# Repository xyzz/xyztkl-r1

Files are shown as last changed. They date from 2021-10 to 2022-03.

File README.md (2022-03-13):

# A second revision of this case design is available at [https://github.com/xyzz/xyztkl-r2](https://github.com/xyzz/xyztkl-r2)

# xyztkl rev1

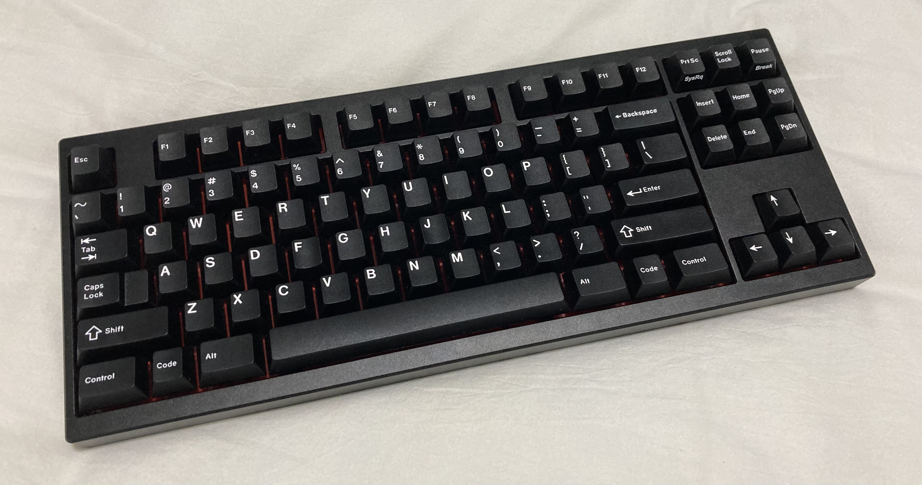
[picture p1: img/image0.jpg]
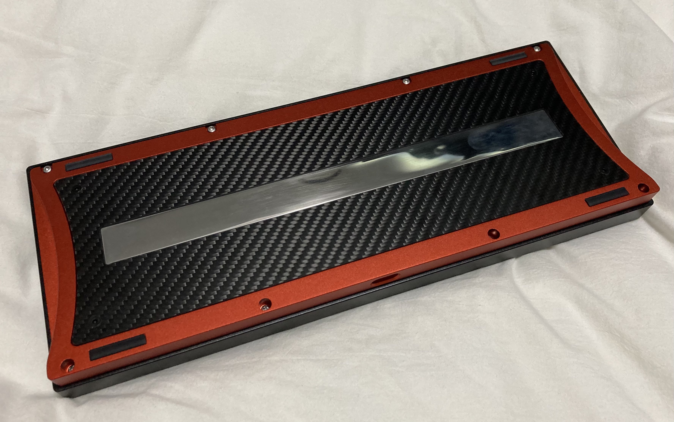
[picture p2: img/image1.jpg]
 

## License

CC0 apart from the switch footprints and component STEP models, see LICENSE.txt.

## Known issues

- The PCB is a bit hard to align
- The steel piece is very long and thin, it may warp during machining

## Parts list

- top
- bottom
- weight-inside: you need two of these, it is already noted in the tech drawing
- weight-outside
- cf-accent: while provided .STEP is 2mm thick, recommend reducing to ~1.8mm so that it looks nicer around the SS accent; countersunk screw holes
- dboard - this uses a custom daughterboard. See notes about JST cable before; should be 1mm thick
- pcb - the included PCB is using STM32F103 (or a compatible clone), you will need an ST-LINK to program the included bootloader; recommend matching the color to the color of the bottom piece if possible; should be 1.6mm thick
- jst cable: 100mm, reverse orientation (pins 1-4 on one side map to 4-1 on the other) - note that this is the opposite of what ai03 unified daughterboard uses, if you use a wrong cable you risk killing the pcb

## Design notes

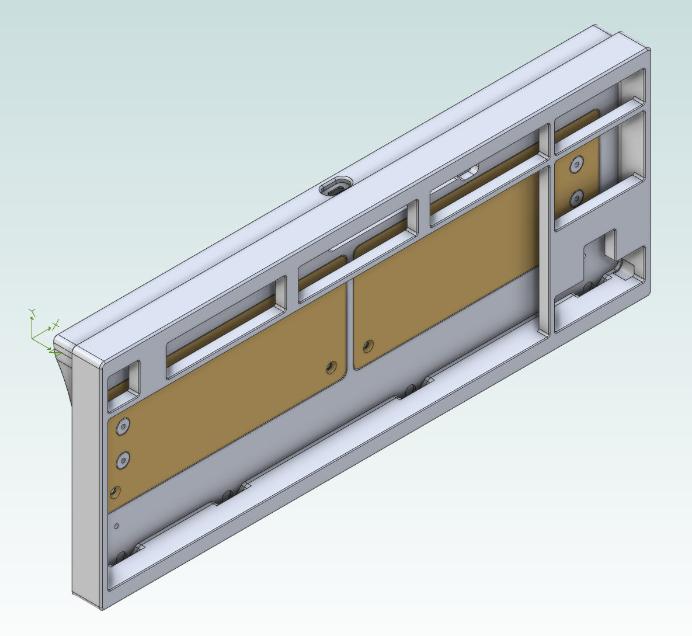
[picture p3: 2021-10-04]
cosmetic/overall-01.png

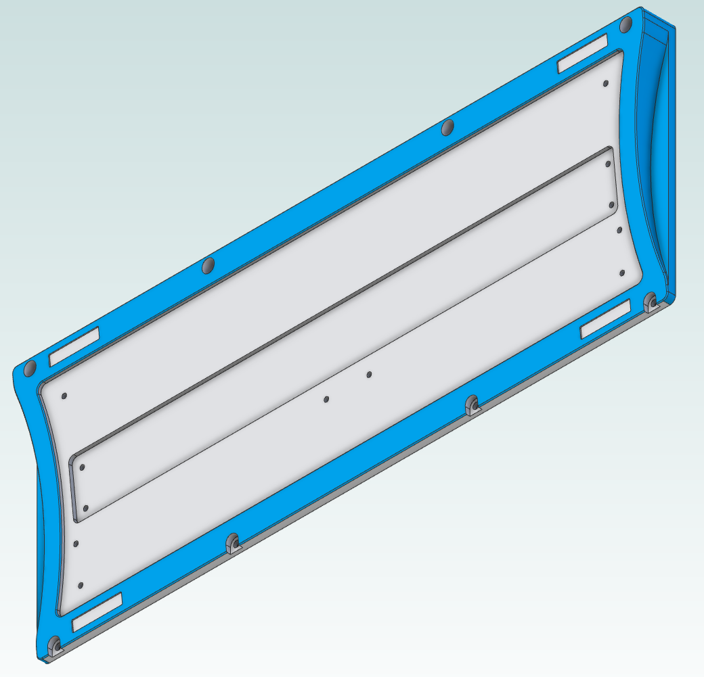
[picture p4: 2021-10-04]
cosmetic/bottom-03.png

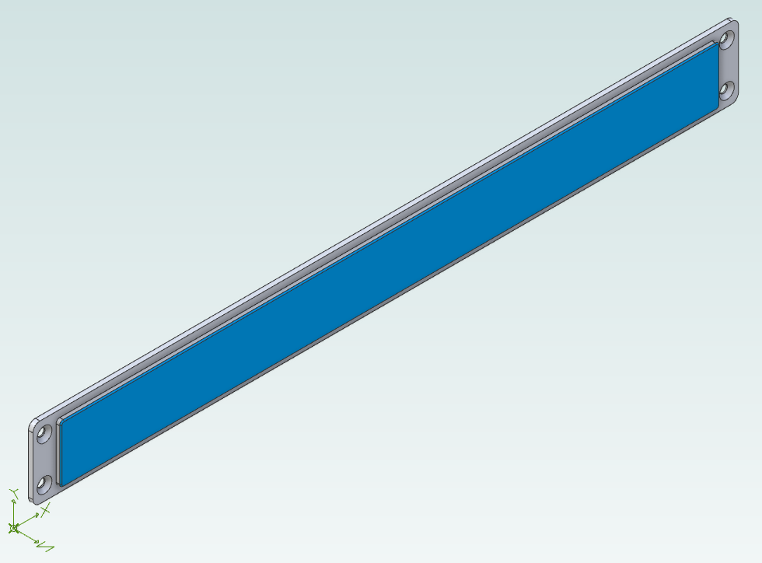
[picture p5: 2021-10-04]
cosmetic/weight-outside-01.png

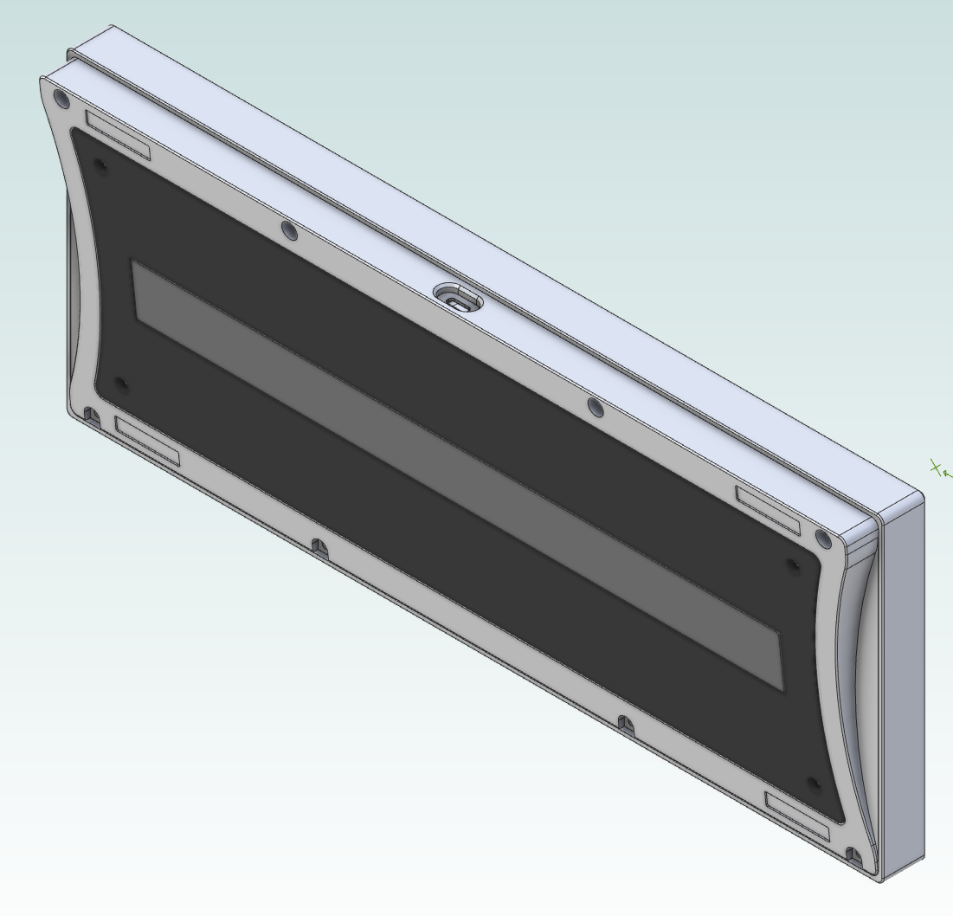
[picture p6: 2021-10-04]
cosmetic/overall-02.png

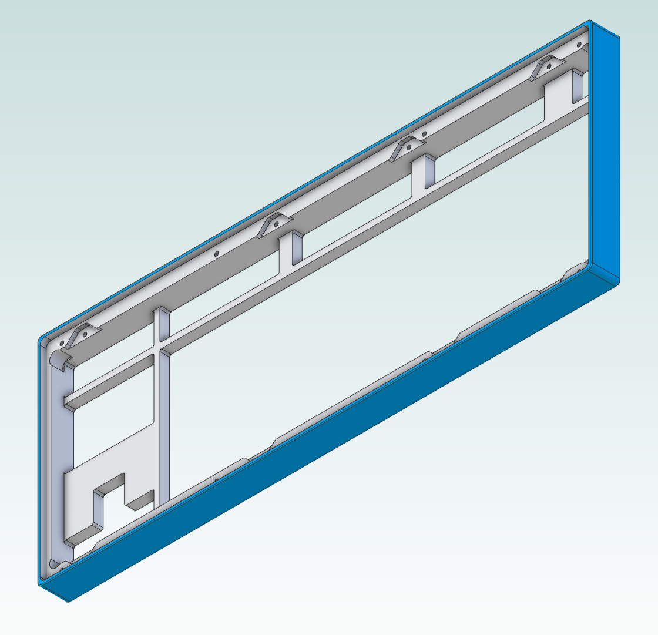
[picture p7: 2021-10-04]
cosmetic/top-03.png

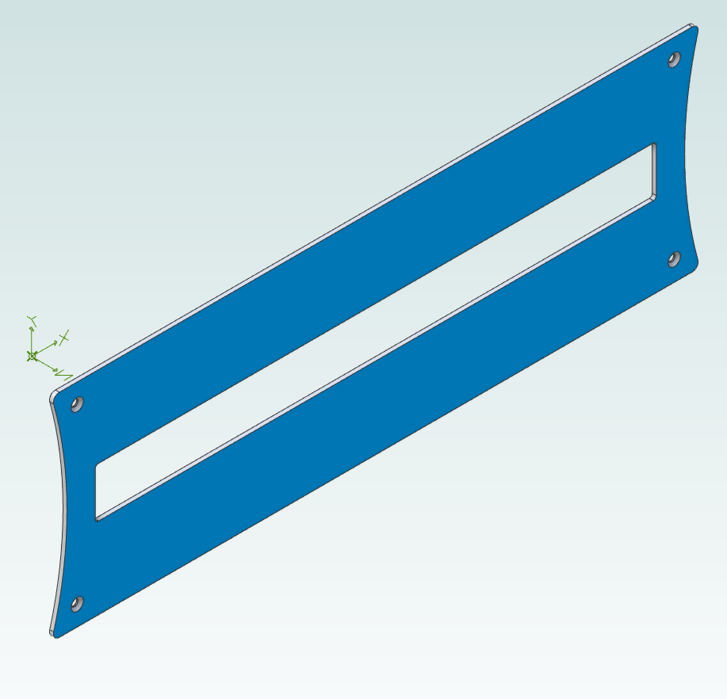
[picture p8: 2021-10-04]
cosmetic/cf-accent-01.png

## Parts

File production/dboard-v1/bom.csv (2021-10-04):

Comment | Designator | Footprint | LCSC
5.1k | R2,R1 | Resistor_SMD:R_0603_1608Metric | C23186
Mount-M2 | MH1,MH2 | MountingHole:MountingHole_3.2mm_M3_Pad_Via
1M | R3 | Resistor_SMD:R_0805_2012Metric | C17514
4.7n | C1 | Capacitor_SMD:C_0603_1608Metric | C53987
USB_C_Receptacle_USB2.0 | J1 | Connector_USB:USB_C_Receptacle_HRO_TYPE-C-31-M-12 | C165948
Conn_01x04_MountingPin | J2 | Connector_JST:JST_SH_SM04B-SRSS-TB_1x04-1MP_P1.00mm_Horizontal | C160404

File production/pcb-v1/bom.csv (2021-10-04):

Comment | Designator | Footprint | LCSC
KEYSW | K_0,K_1,K_2,K_3,K_4,K_5,K_6,K_7,K_8,K_9,K_10,K_11,K_12,K_13,K_15,K_16,K_17,K_18,K_19,K_20,K_21,K_22,K_23,K_24,K_25,K_26,K_27,K_28,K_29,K_30,K_31,K_32,K_33,K_35,K_36,K_37,K_38,K_39,K_40,K_41,K_42,K_43,K_44,K_45,K_46,K_48,K_49,K_50,K_52,K_53,K_54,K_55,K_56,K_57,K_58,K_59,K_60,K_61,K_62,K_65,K_66,K_67,K_68,K_69,K_70,K_71,K_72,K_73,K_74,K_76,K_77,K_86,K_87,K_88 | MX_Only:MXOnly-1U-NoLED
D | D_0,D_1,D_2,D_3,D_4,D_5,D_6,D_7,D_8,D_9,D_10,D_11,D_12,D_13,D_14,D_15,D_16,D_17,D_18,D_19,D_20,D_21,D_22,D_23,D_24,D_25,D_26,D_27,D_28,D_29,D_30,D_31,D_32,D_33,D_34,D_35,D_36,D_37,D_38,D_39,D_40,D_41,D_42,D_43,D_44,D_45,D_46,D_47,D_48,D_49,D_50,D_51,D_52,D_53,D_54,D_55,D_56,D_57,D_58,D_59,D_60,D_61,D_62,D_63,D_64,D_65,D_66,D_67,D_68,D_69,D_70,D_71,D_72,D_73,D_74,D_75,D_76,D_77,D_78,D_79,D_80,D_81,D_82,D_83,D_84,D_85,D_86,D_87,D_88 | Diode_SMD:D_SOD-123 | C81598
KEYSW | K_14 | MX_Only:MXOnly-1U
KEYSW | K_34,K_47 | MX_Only:MXOnly-1.5U-NoLED
KEYSW | K_51 | MX_Only:MXOnly-1.75U
KEYSW | K_63,K_64 | MX_Only:MXOnly-2.25U-NoLED
KEYSW | K_75 | MX_Only:MXOnly-1.75U-NoLED
1.25 | K_78,K_79,K_80,K_82,K_83,K_84,K_85 | MX_Only:MXOnly-1.25U-NoLED
6.25 | K_81 | MX_Only:MXOnly-6.25U-ReversedStabilizers-NoLED
~7 | K_181 | MX_Only:MXOnly-7U-ReversedStabilizers-NoLED
~1.5 | K_178,K_180,K_183,K_185 | MX_Only:MXOnly-1.5U-NoLED
~1 | K_179,K_184 | MX_Only:MXOnly-1U-NoLED
Conn_01x04 | J1 | Connector_JST:JST_SH_SM04B-SRSS-TB_1x04-1MP_P1.00mm_Horizontal | C160404
MX-NoLED | K_175 | MX_Only:MXOnly-2.75U-NoLED
MX-NoLED | K_130 | MX_Only:MXOnly-2U-NoLED
8MHz | Y1 | Crystal:Crystal_SMD_5032-2Pin_5.0x3.2mm | C115962
20p | C9,C10 | Capacitor_SMD:C_0603_1608Metric | C1648
10u | C7 | Capacitor_SMD:C_0603_1608Metric | C19702
100n | C2,C3,C4,C5,C6,C8 | Capacitor_SMD:C_0603_1608Metric | C14663
10k | R1 | Resistor_SMD:R_0603_1608Metric | C25804
STM32F103C8Tx | U3 | Package_QFP:LQFP-48_7x7mm_P0.5mm
1u | C1,C12,C11 | Capacitor_SMD:C_0603_1608Metric | C15849
SWDIO | J3 | TestPoint:TestPoint_Pad_D1.5mm
SWCLK | J4 | TestPoint:TestPoint_Pad_D1.5mm
GND | J5 | TestPoint:TestPoint_Pad_D1.5mm
XC6206P332MR | U2 | Package_TO_SOT_SMD:SOT-23 | C5446
500mA | F1 | Fuse:Fuse_1206_3216Metric | C369159
1.5k | R2 | Resistor_SMD:R_0603_1608Metric | C22843
3.3v | J2 | TestPoint:TestPoint_Pad_D1.5mm
SRV05-4 | U1 | Package_TO_SOT_SMD:SOT-23-6 | C85364
MX-NoLED | K_151 | MX_Only:MXOnly-1.25U-FLIPPED
680 | R3,R4 | Resistor_SMD:R_0603_1608Metric | C23228

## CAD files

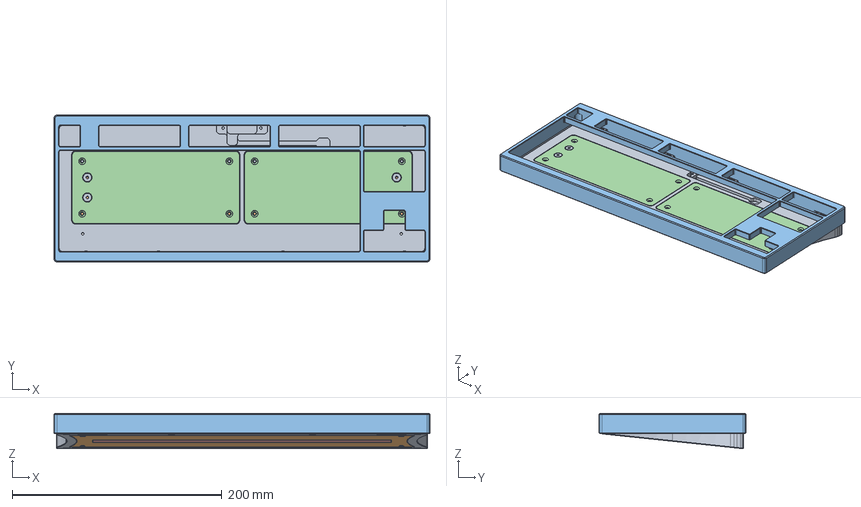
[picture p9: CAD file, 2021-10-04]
assembled.stp
358.6 x 140.0 x 33.7 mm
bottom
cf-accent
top
weight-inside x 2
weight-outside

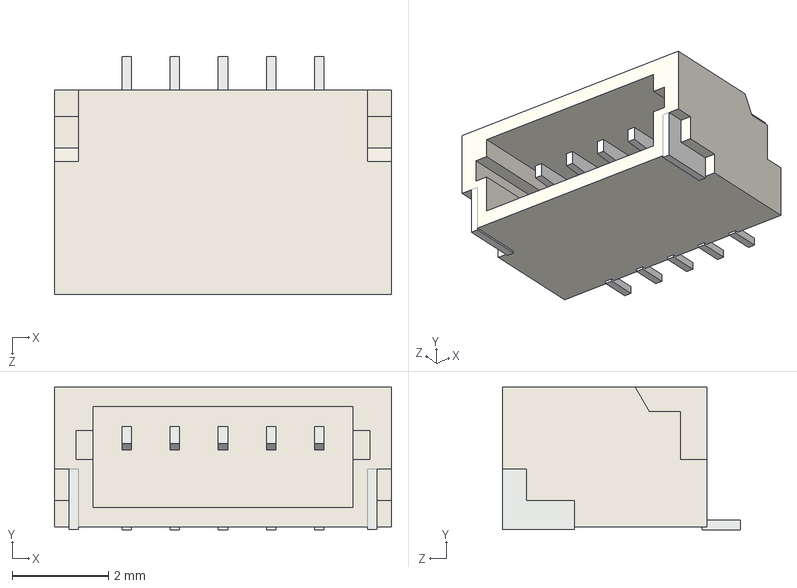
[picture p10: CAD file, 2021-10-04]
dboard/JST_SM05B-SRSS-TB.STEP
7.00 x 2.96 x 4.95 mm

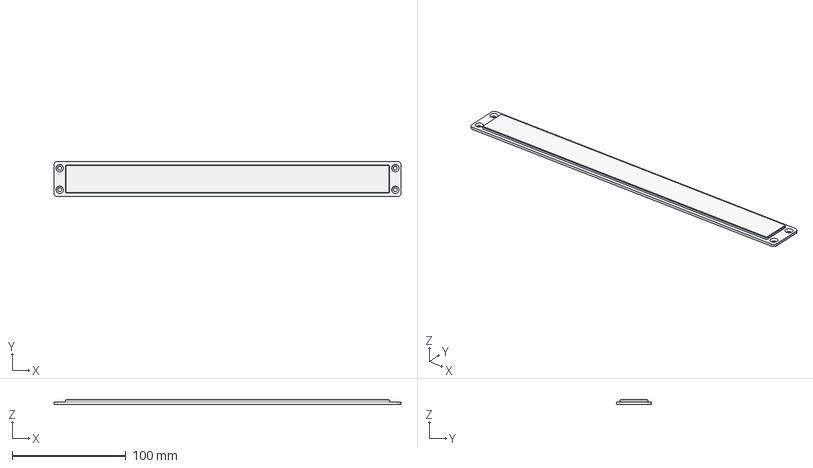
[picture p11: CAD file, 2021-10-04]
parts/weight-outside.stp
305.0 x 31.0 x 4.00 mm

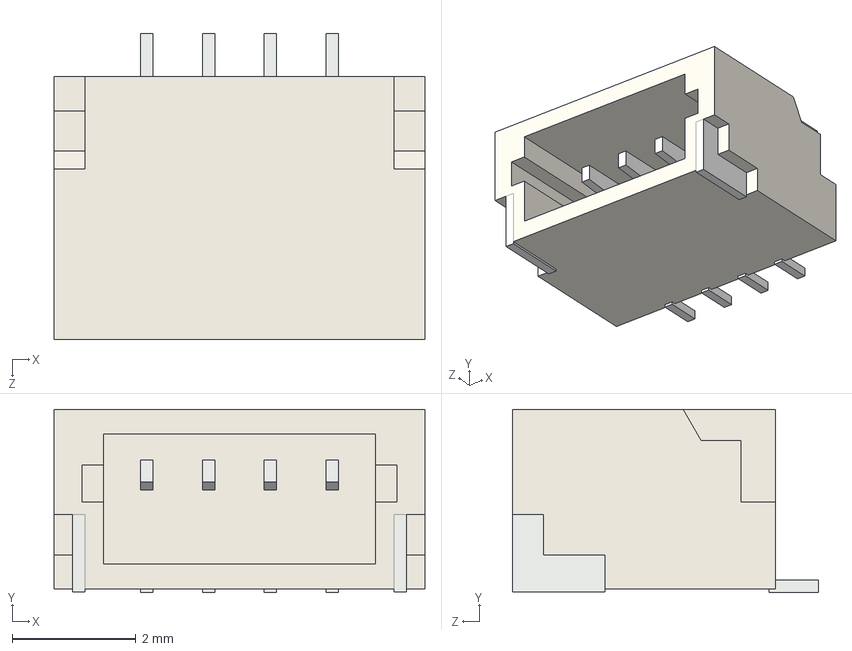
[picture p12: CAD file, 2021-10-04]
pcb/JST-SM04B-SRSS-TB.STEP
6.00 x 2.96 x 4.95 mm

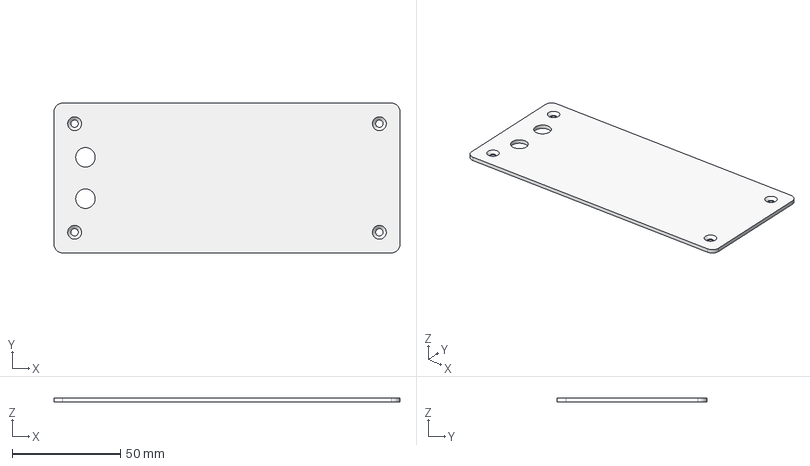
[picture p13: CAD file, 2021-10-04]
parts/weight-inside.stp
159.5 x 69.0 x 2.00 mm

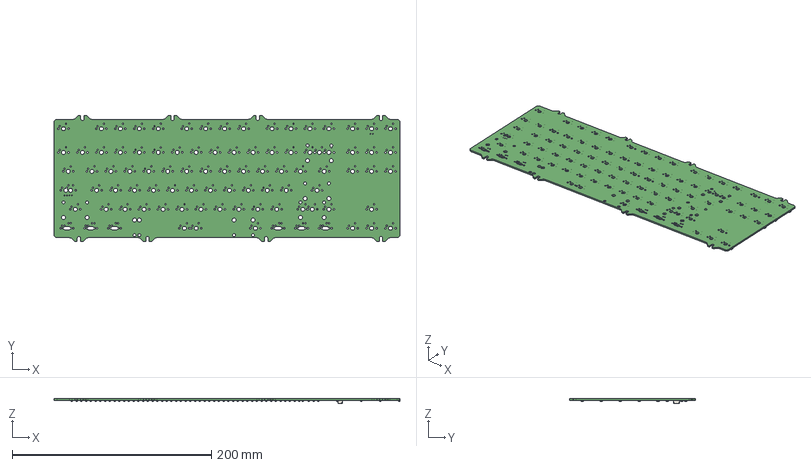
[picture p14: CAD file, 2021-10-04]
pcb/keyboard.step
347.7 x 127.1 x 4.66 mm

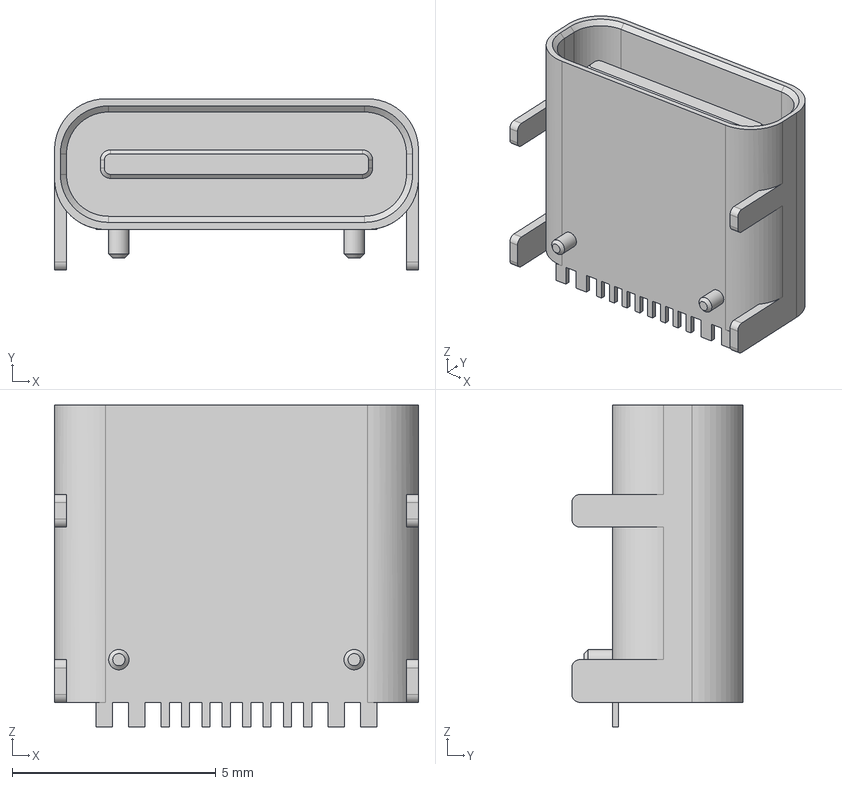
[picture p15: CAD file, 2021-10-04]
dboard/HRO-TYPE-C-31-M-12.step
8.94 x 4.21 x 7.90 mm

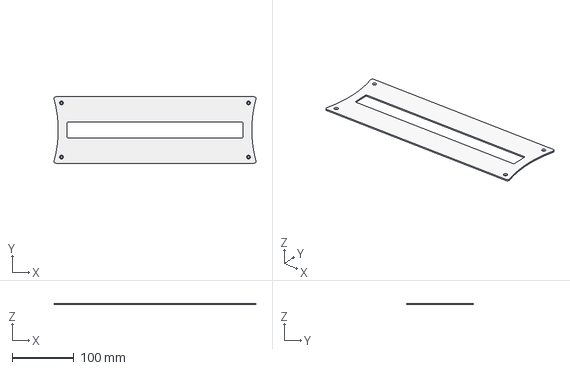
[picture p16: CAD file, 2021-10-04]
parts/cf-accent.stp
328.0 x 108.0 x 2.00 mm

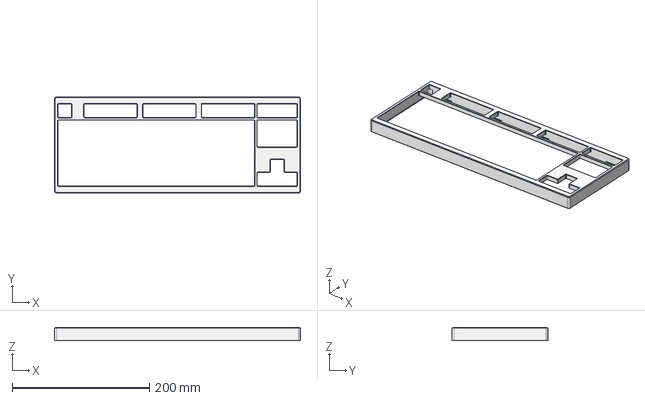
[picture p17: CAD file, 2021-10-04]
parts/top.stp
358.6 x 140.0 x 19.3 mm

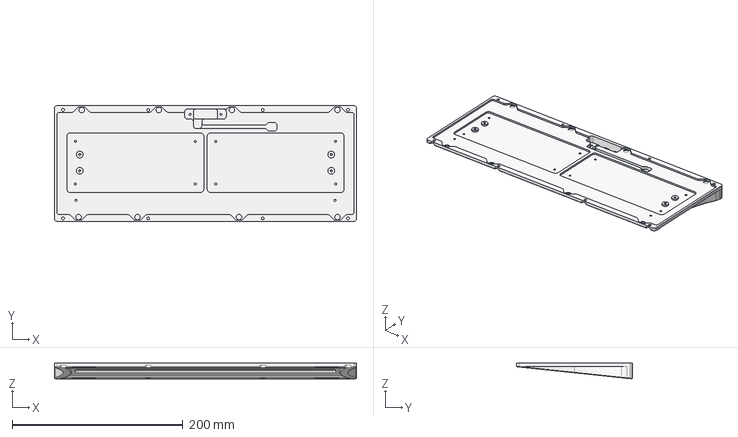
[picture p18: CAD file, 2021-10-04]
parts/bottom.stp
354.2 x 135.6 x 18.4 mm

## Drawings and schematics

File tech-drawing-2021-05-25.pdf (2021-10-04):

Scale | Sheet
1:1 | 1 OF 13

### Cosmetic requirements for surfaces indicated in BLUE - No scratches, dents, marks - Consistent anodization finish: no discoloration, no blemishes - No hanging/hook marks

### See included QC.PDF for more detail

Version 2021-05-21

### Part list: - bottom.step - top.step - (2x) weight-inside.step - weight-outside.step - cf-accent.step

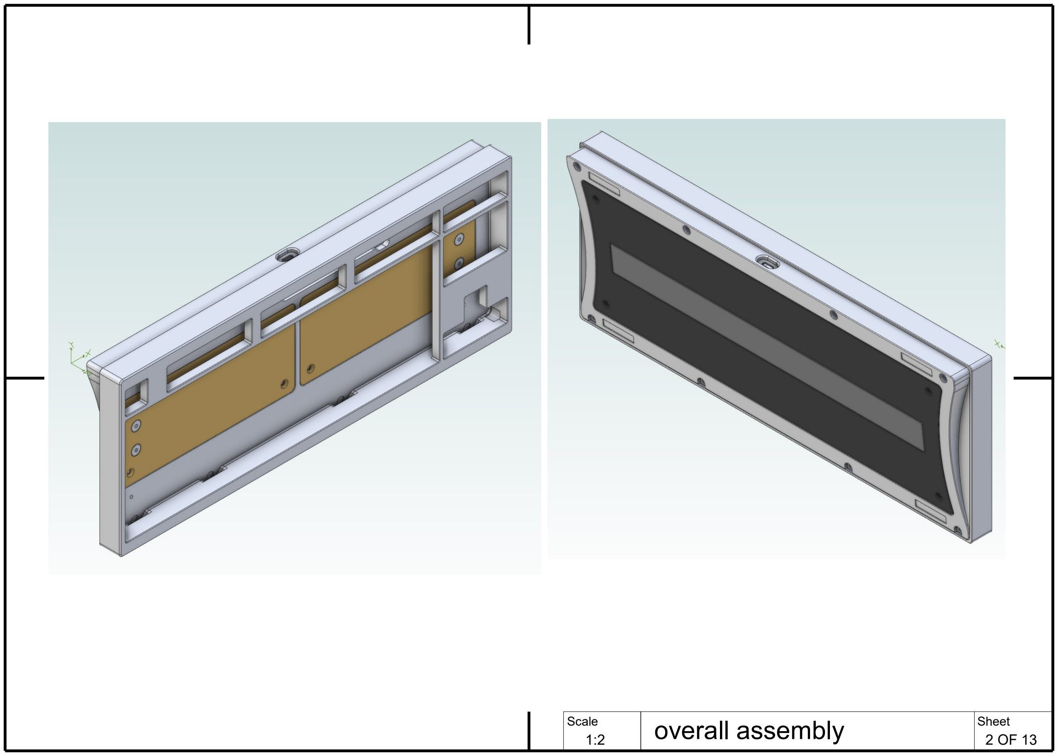
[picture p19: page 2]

Scale | | Sheet
1:2 | overall assembly | 2 OF 13

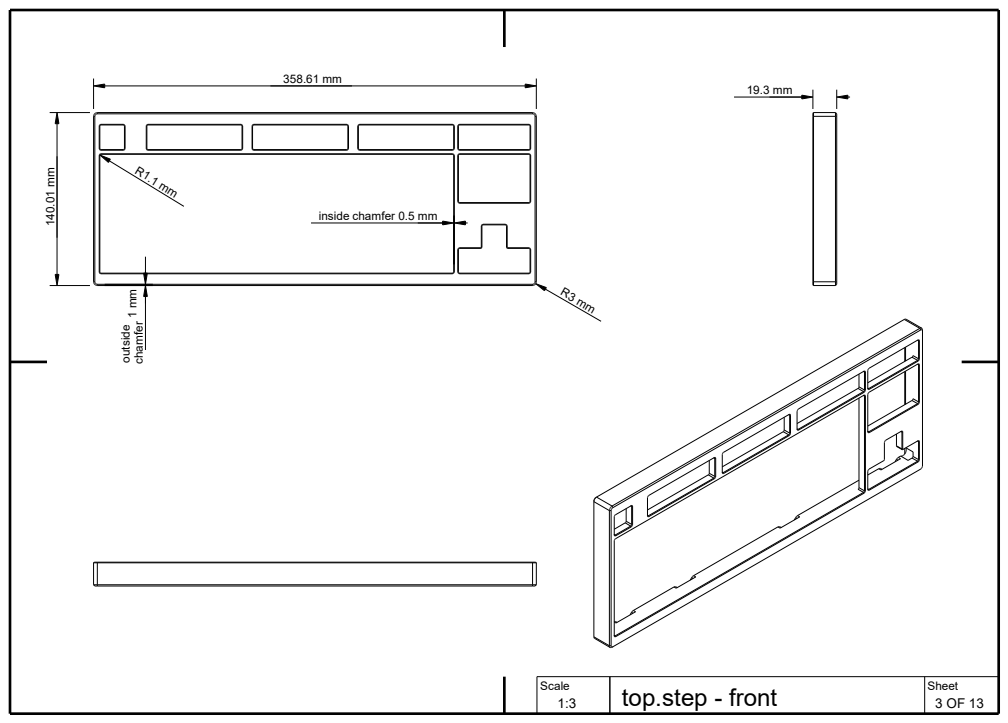
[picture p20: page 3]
Scale; Sheet; top.step - front

R1.1 mm 1 mm outside chamfer

inside chamfer 0.5 mm

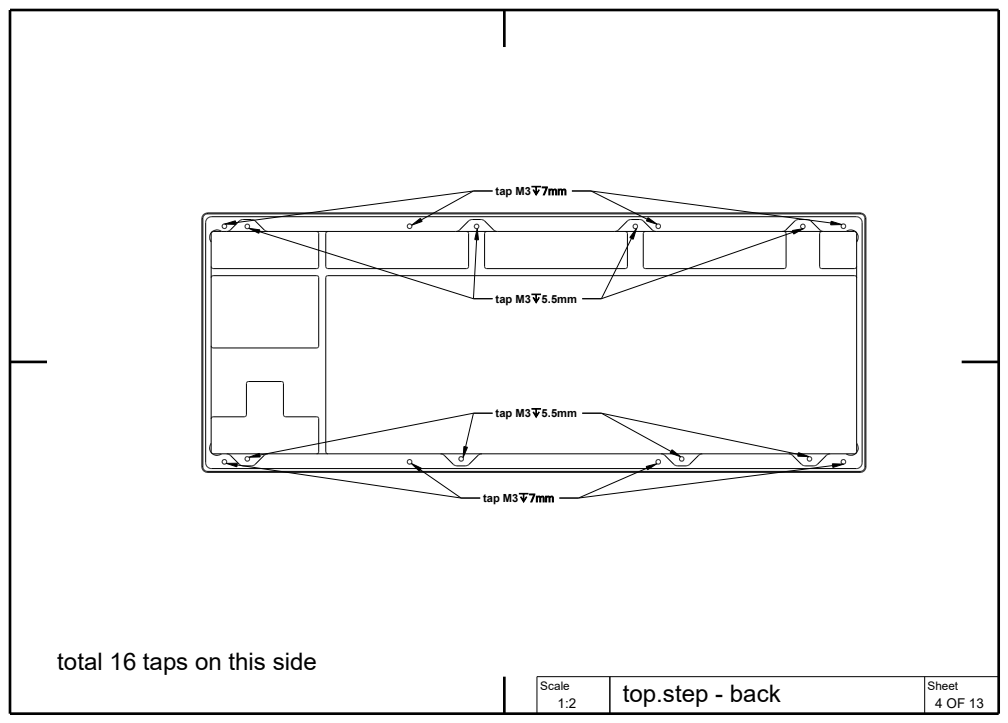
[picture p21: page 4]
tap M3x7mm; tap M3x5.5mm; Scale; Sheet

total 16 taps on this side

top.step - back

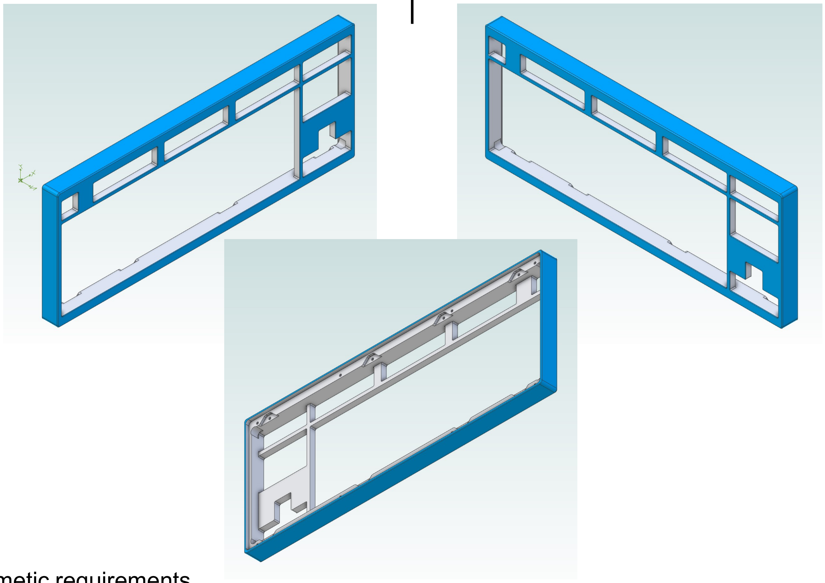
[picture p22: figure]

Scale | Sheet
1:2 | 5 OF 13 top.step - cosmetic surfaces

cosmetic requirements
for surfaces indicated in BLUE
see first page and QC.PDF for details

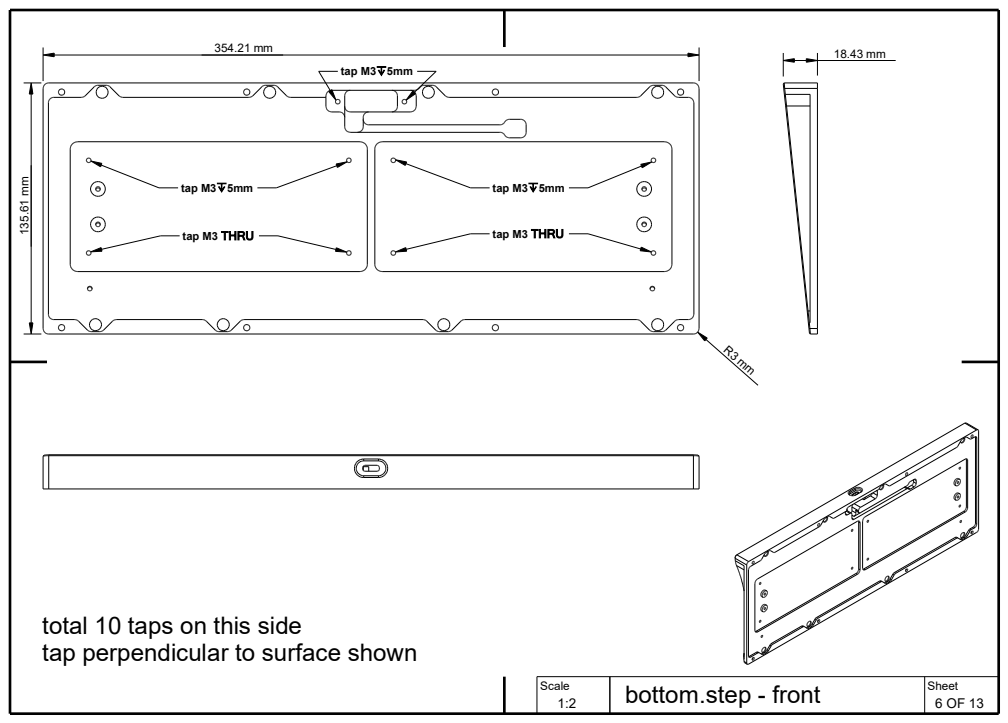
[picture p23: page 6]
tap M3x5mm; tap M3 THRU; Scale; Sheet

total 10 taps on this side
tap perpendicular to surface shown

bottom.step - front

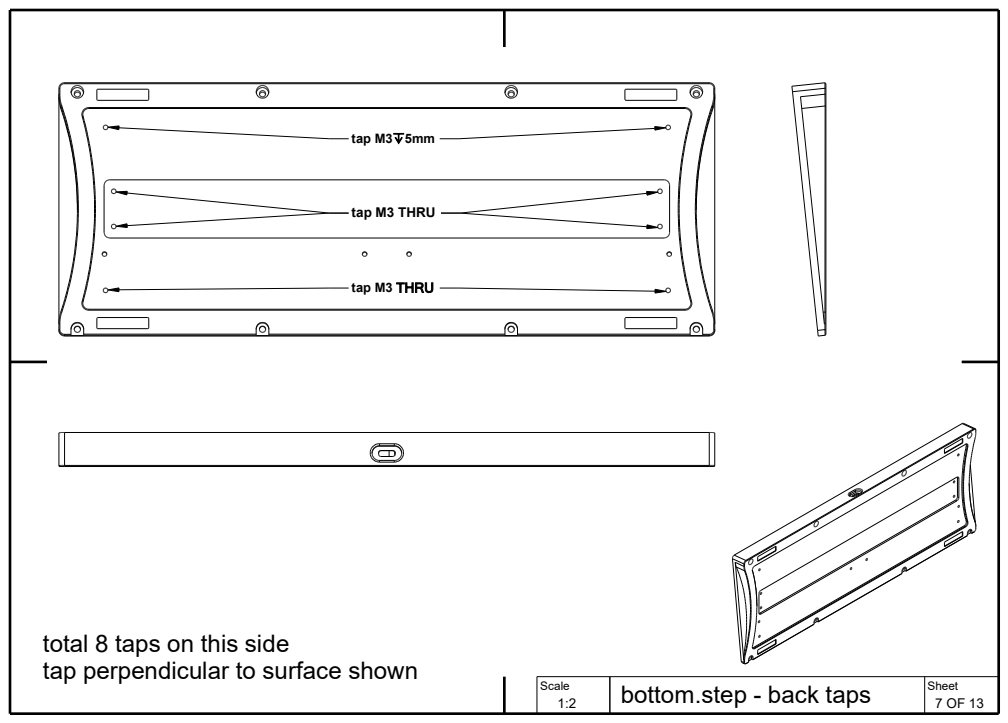
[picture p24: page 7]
tap M3 THRU; tap M3x5mm; Scale; Sheet; bottom.step - back taps

total 8 taps on this side
tap perpendicular to surface shown

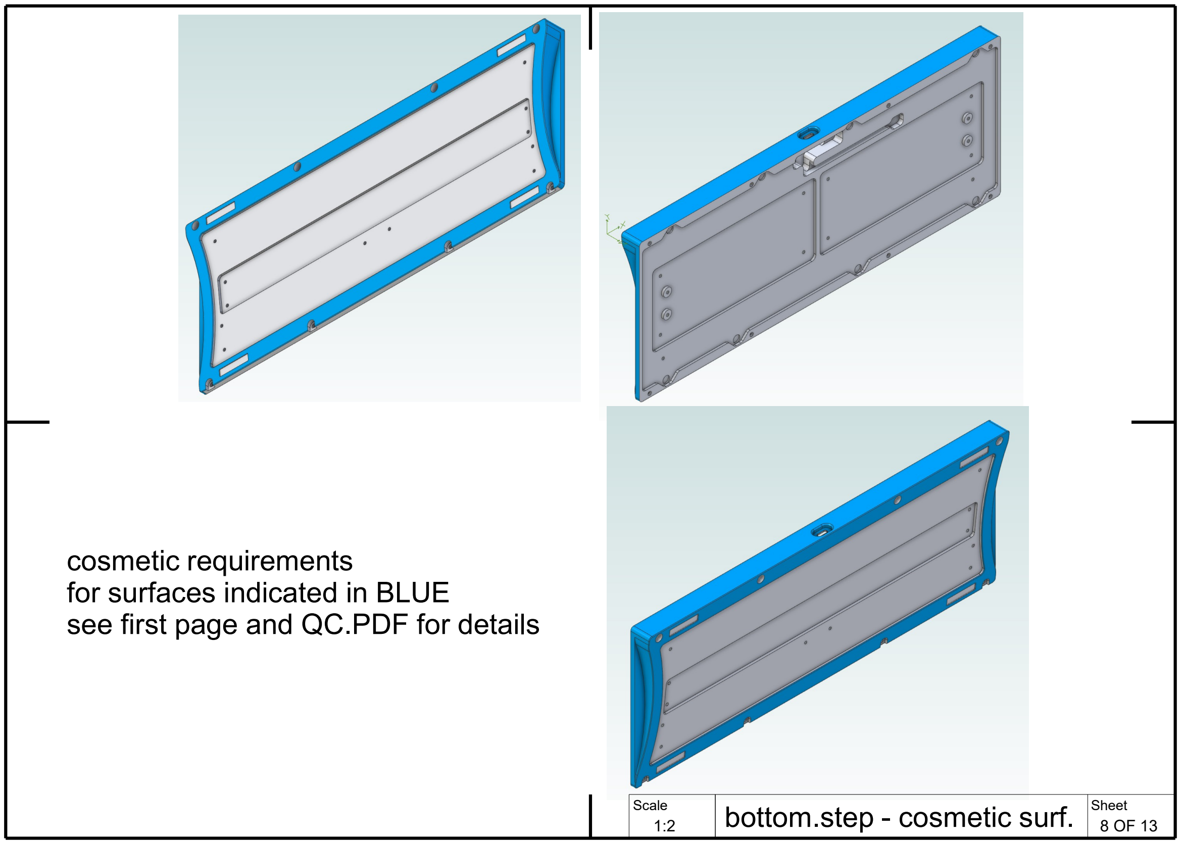
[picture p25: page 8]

Scale | Sheet
1:2 | 8 OF 13

cosmetic requirements
for surfaces indicated in BLUE
see first page and QC.PDF for details

bottom.step - cosmetic surf.

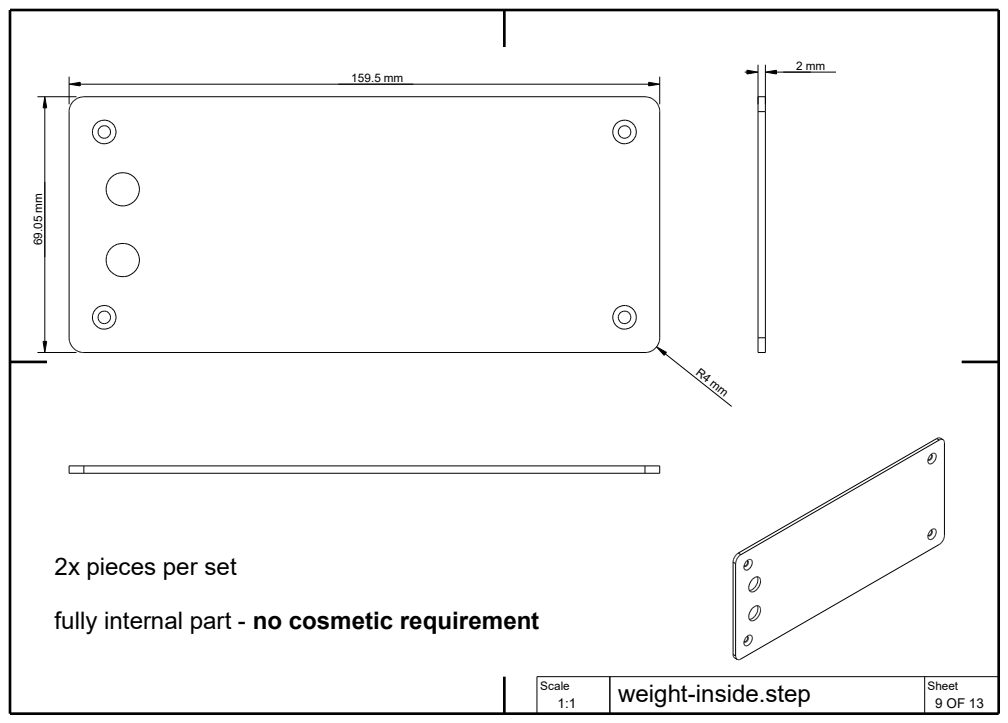
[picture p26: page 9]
Scale; Sheet; weight-inside.step

2x pieces per set

fully internal part - no cosmetic requirement

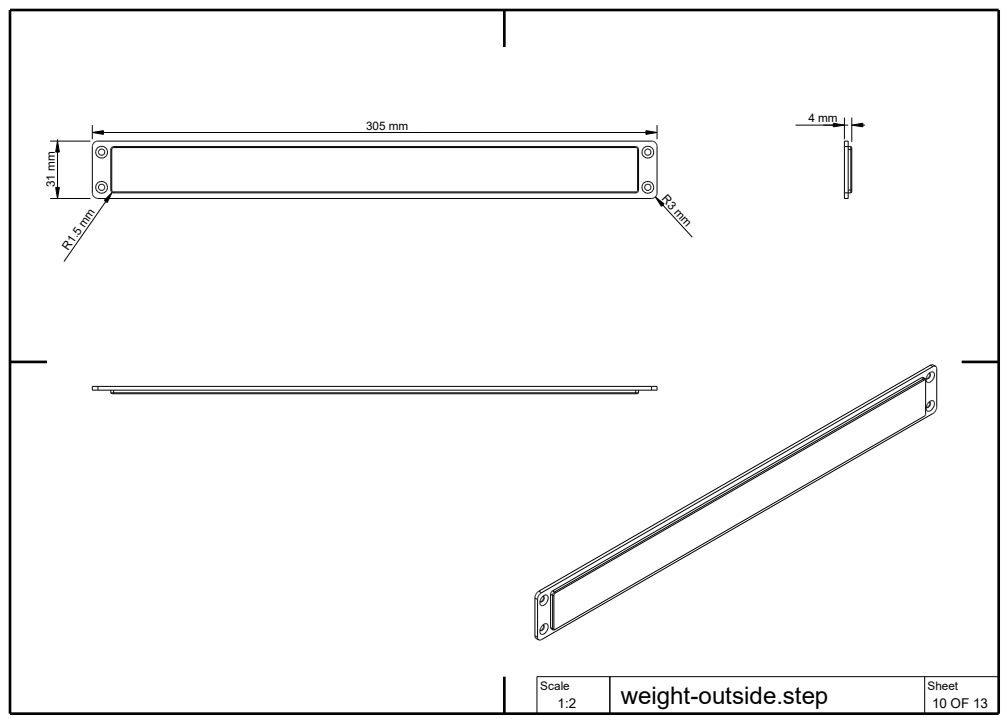
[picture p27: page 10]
Scale; Sheet; weight-outside.step

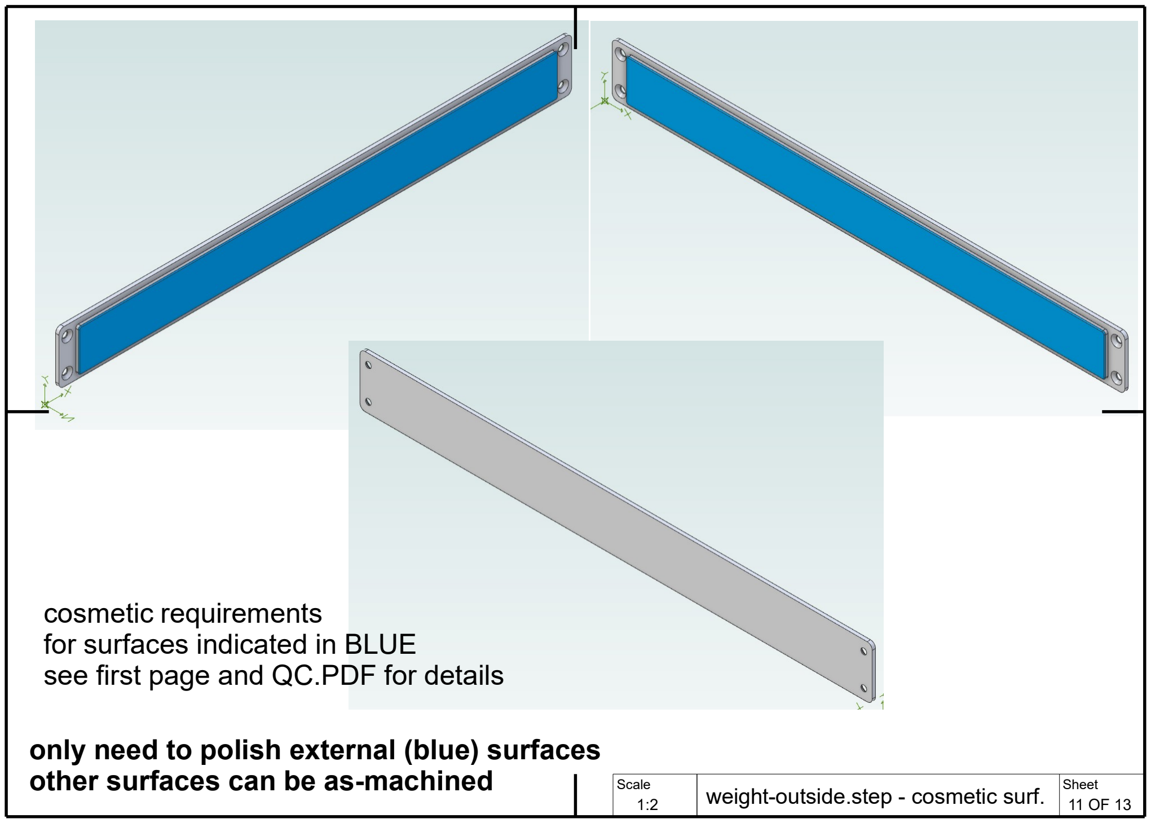
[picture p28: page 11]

Scale | | Sheet
1:2 | weight-outside.step - cosmetic surf. | 11 OF 13

cosmetic requirements
for surfaces indicated in BLUE
see first page and QC.PDF for details

only need to polish external (blue) surfaces other surfaces can be as-machined

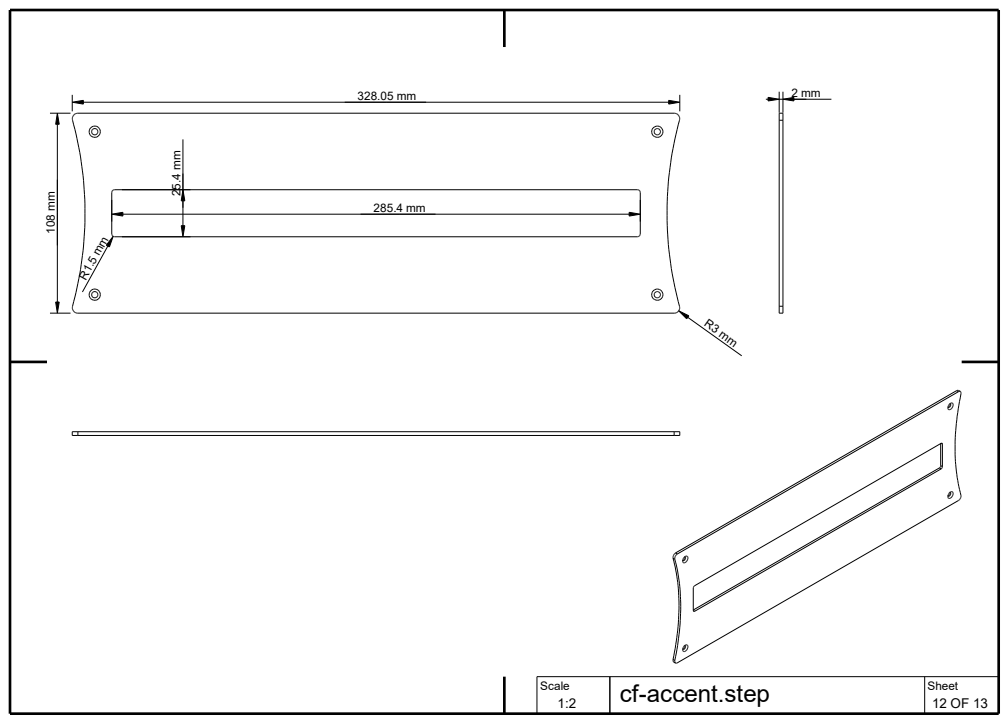
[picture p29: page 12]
Scale; Sheet; cf-accent.step

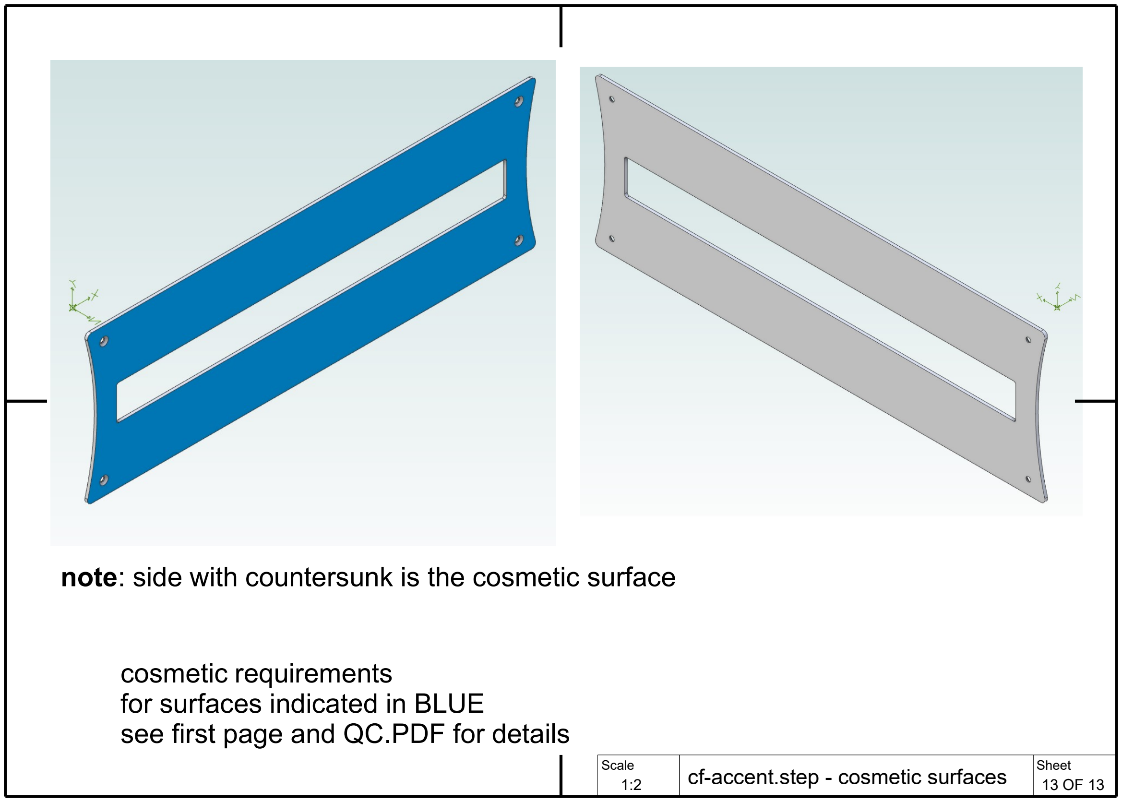
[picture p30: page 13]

Scale | Sheet
1:2 | 13 OF 13 cf-accent.step - cosmetic surfaces

cosmetic requirements
for surfaces indicated in BLUE
see first page and QC.PDF for details note: side with countersunk is the cosmetic surface

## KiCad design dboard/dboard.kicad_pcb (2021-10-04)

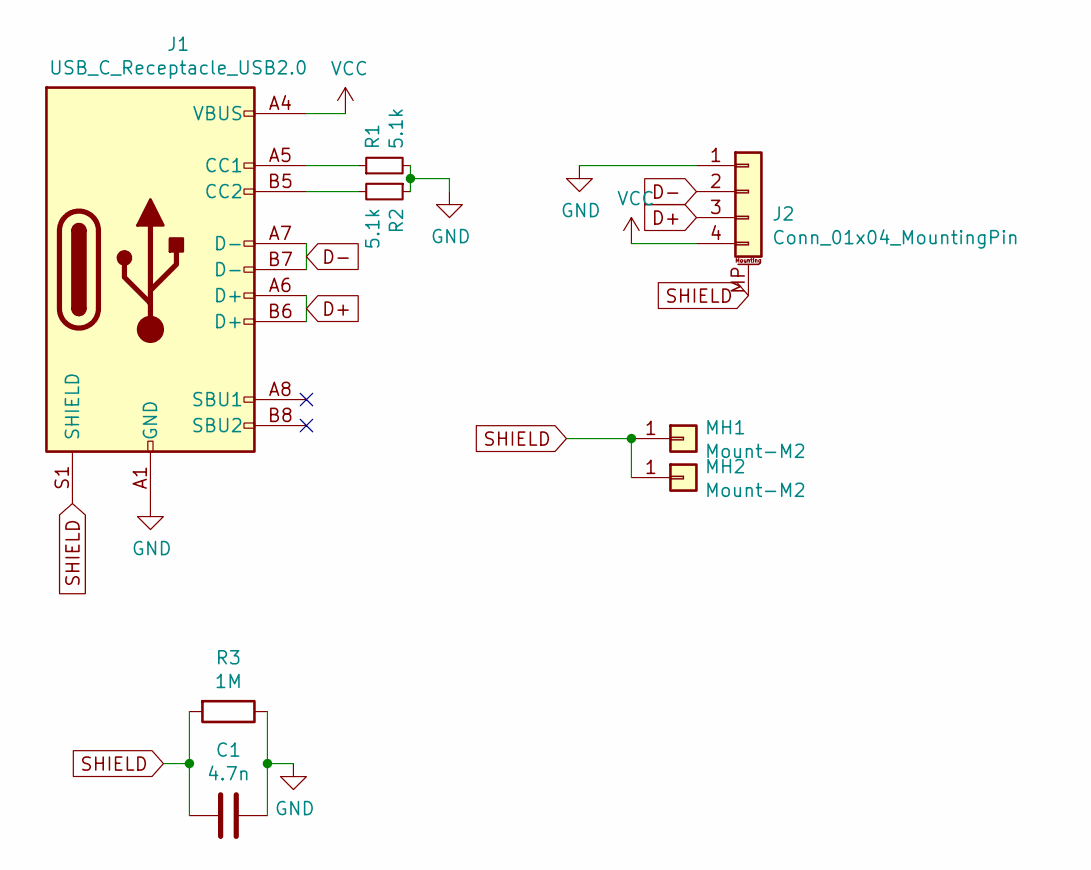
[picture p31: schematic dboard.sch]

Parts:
C1: 4.7n; C_0603_1608Metric; LCSC C53987
J1: USB_C_Receptacle_USB2.0; USB_C_Receptacle_HRO_TYPE-C-31-M-12; LCSC C165948
J2: Conn_01x04_MountingPin; JST_SH_SM04B-SRSS-TB_1x04-1MP_P1.00mm_Horizontal; LCSC C160404
MH1, MH2: Mount-M2; MountingHole_3.2mm_M3_Pad_Via
R1, R2: 5.1k; R_0603_1608Metric; LCSC C23186
R3: 1M; R_0805_2012Metric; LCSC C17514

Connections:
D+: J1.A6 (D+), J1.B6 (D+), J2.3
D-: J1.A7 (D-), J1.B7 (D-), J2.2
GND: C1.1, J1.A1 (GND), J1.A12 (GND), J1.B1 (GND), J1.B12 (GND), J2.1, R1.2, R2.1, R3.1
unnamed: J1.A5 (CC1), R1.1
unnamed: J1.B5 (CC2), R2.2
SHIELD: C1.2, J1.S1 (SHIELD), J2.MP (MountPin), MH1.1, MH2.1, R3.2
VCC: J1.A4 (VBUS), J1.A9 (VBUS), J1.B4 (VBUS), J1.B9 (VBUS), J2.4

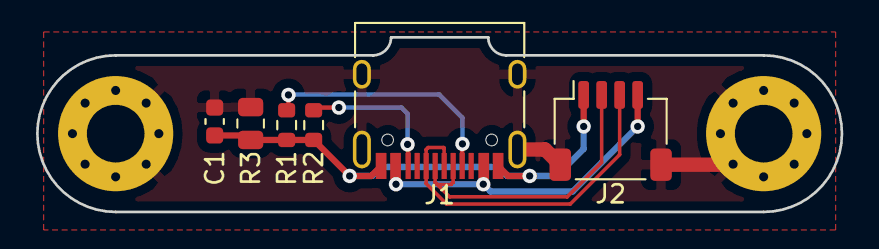
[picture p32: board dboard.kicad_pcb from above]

Board: 2 copper layers, 44.7 x 9.7 mm, 8 parts (0 on the bottom side), 7 nets.

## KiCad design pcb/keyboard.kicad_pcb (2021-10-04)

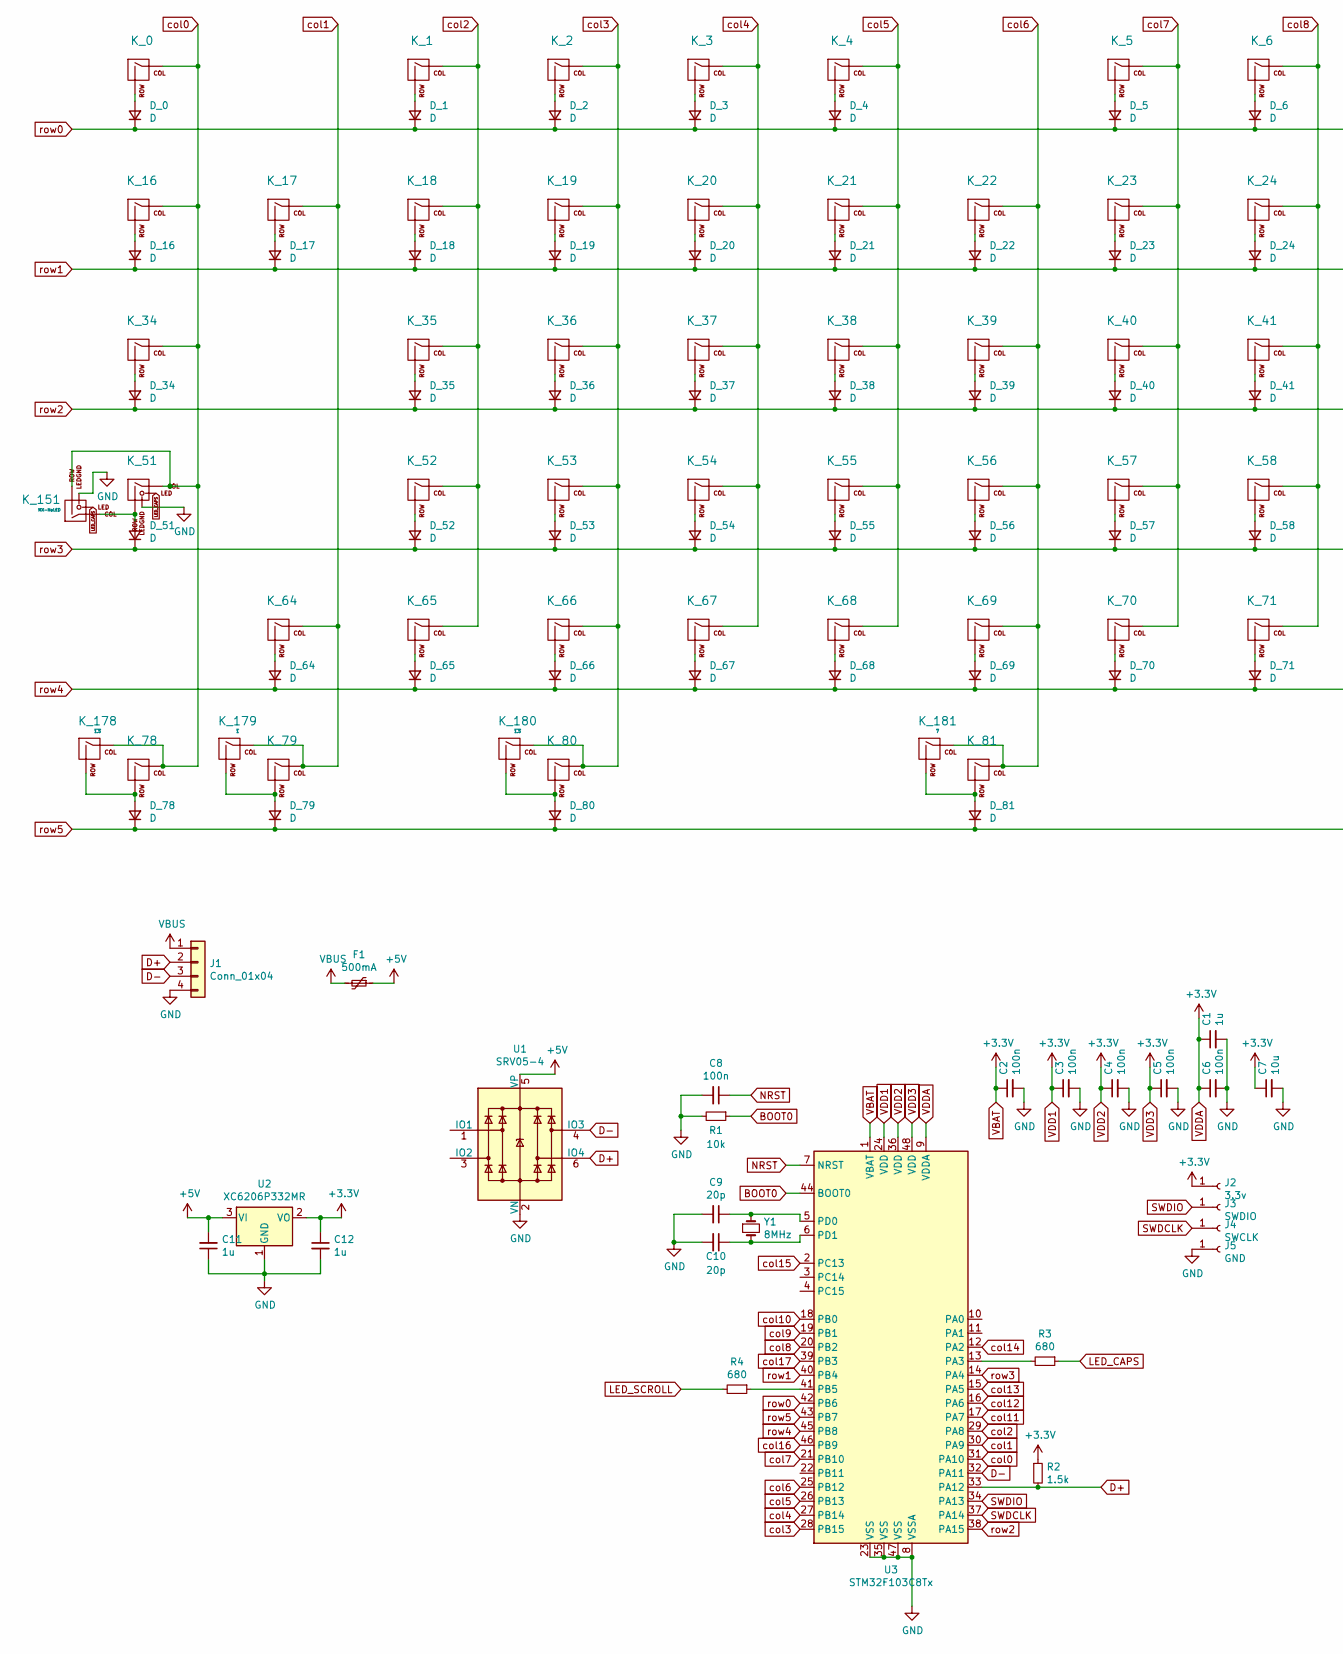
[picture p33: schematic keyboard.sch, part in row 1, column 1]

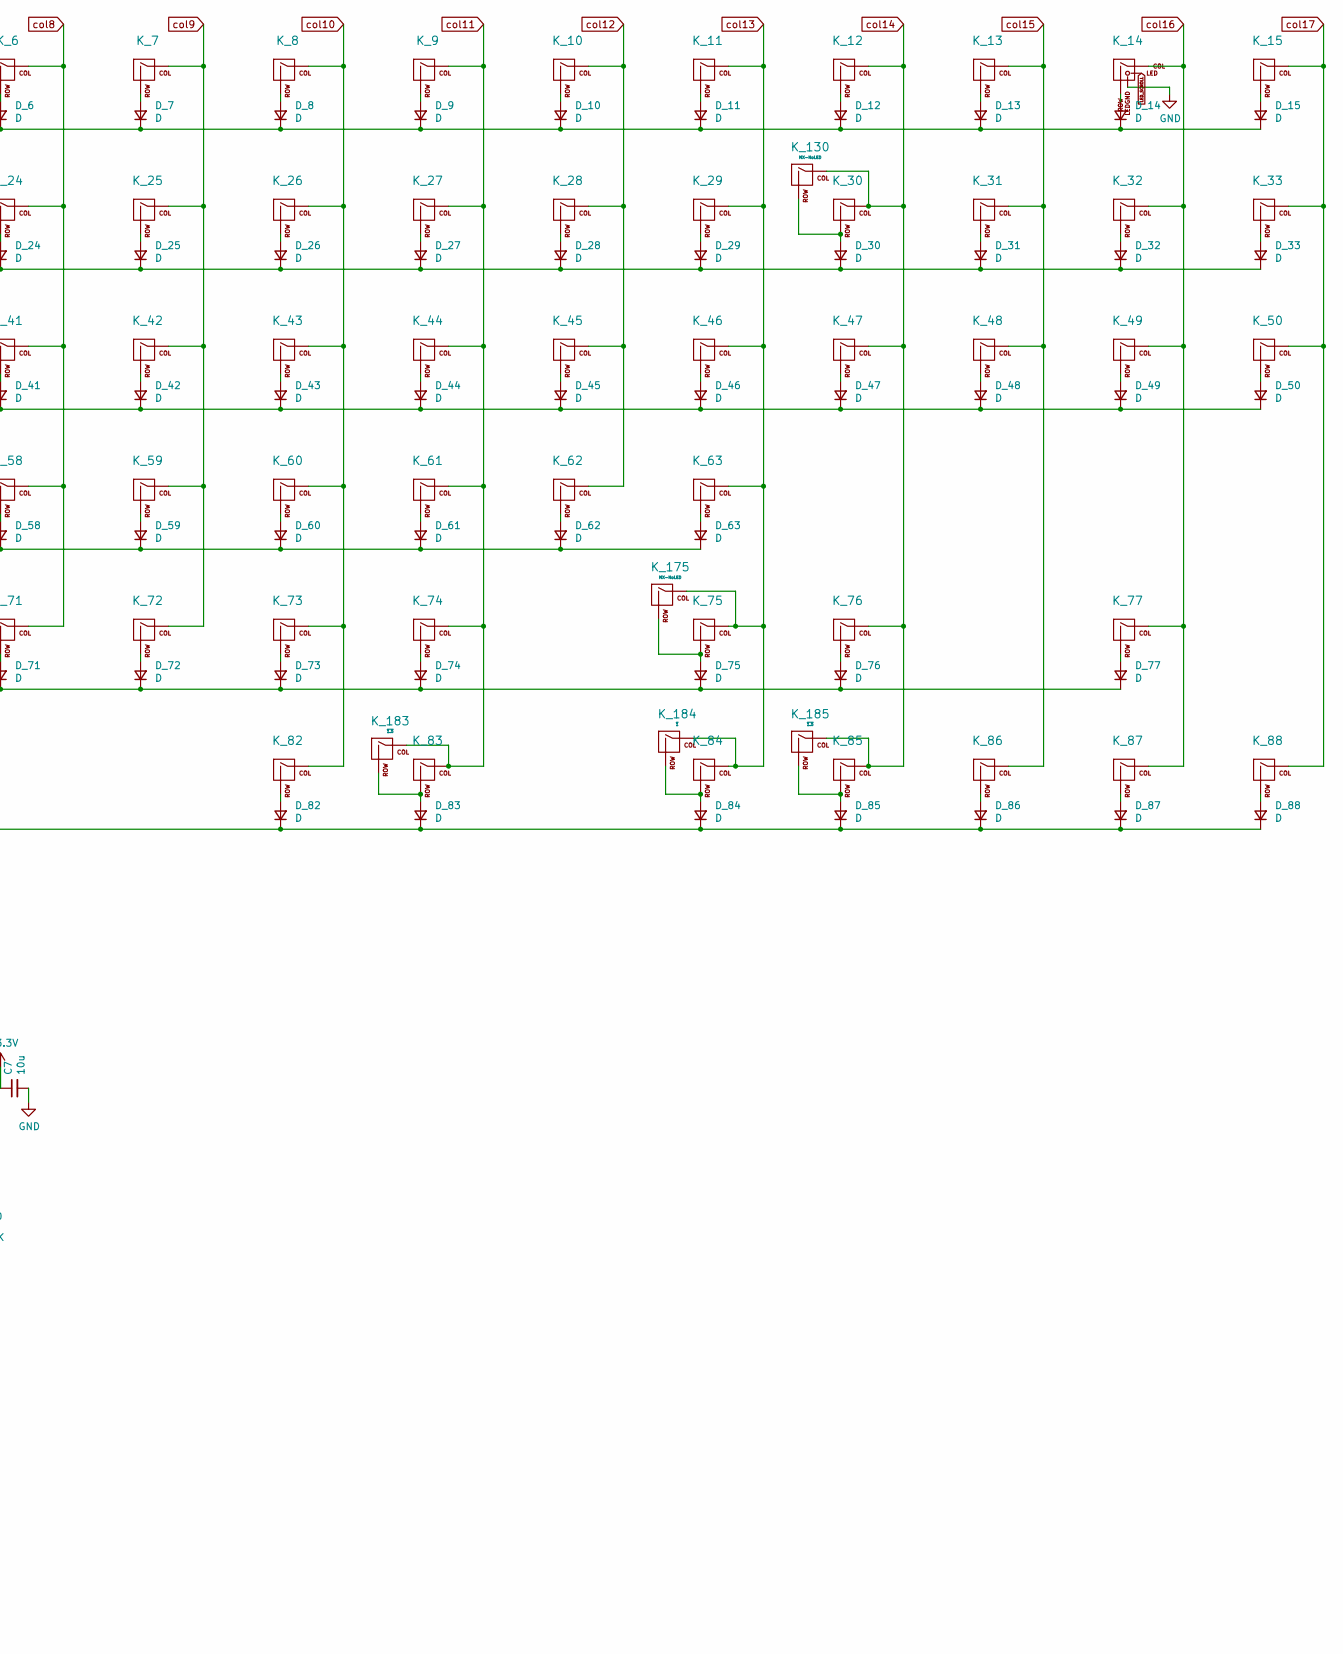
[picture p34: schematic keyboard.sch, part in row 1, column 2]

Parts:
C1, C11, C12: 1u; C_0603_1608Metric; LCSC C15849
C2, C3, C4, C5, C6, C8: 100n; C_0603_1608Metric; LCSC C14663
C7: 10u; C_0603_1608Metric; LCSC C19702
C9, C10: 20p; C_0603_1608Metric; LCSC C1648
D_0, D_1, D_2, D_3, D_4, D_5, D_6, D_7, D_8, D_9, D_10, D_11, D_12, D_13, D_14, D_15, D_16, D_17, D_18, D_19, D_20, D_21, D_22, D_23, D_24, D_25, D_26, D_27, D_28, D_29, D_30, D_31, D_32, D_33, D_34, D_35, D_36, D_37, D_38, D_39, D_40, D_41, D_42, D_43, D_44, D_45, D_46, D_47, D_48, D_49, D_50, D_51, D_52, D_53, D_54, D_55, D_56, D_57, D_58, D_59, D_60, D_61, D_62, D_63, D_64, D_65, D_66, D_67, D_68, D_69, D_70, D_71, D_72, D_73, D_74, D_75, D_76, D_77, D_78, D_79, D_80, D_81, D_82, D_83, D_84, D_85, D_86, D_87, D_88: D; D_SOD-123; LCSC C81598
F1: 500mA; Fuse_1206_3216Metric; LCSC C369159
J1: Conn_01x04; JST_SH_SM04B-SRSS-TB_1x04-1MP_P1.00mm_Horizontal; LCSC C160404
J2: 3.3v; TestPoint_Pad_D1.5mm
J3: SWDIO; TestPoint_Pad_D1.5mm
J4: SWCLK; TestPoint_Pad_D1.5mm
J5: GND; TestPoint_Pad_D1.5mm
K_0, K_1, K_2, K_3, K_4, K_5, K_6, K_7, K_8, K_9, K_10, K_11, K_12, K_13, K_15, K_16, K_17, K_18, K_19, K_20, K_21, K_22, K_23, K_24, K_25, K_26, K_27, K_28, K_29, K_30, K_31, K_32, K_33, K_35, K_36, K_37, K_38, K_39, K_40, K_41, K_42, K_43, K_44, K_45, K_46, K_48, K_49, K_50, K_52, K_53, K_54, K_55, K_56, K_57, K_58, K_59, K_60, K_61, K_62, K_65, K_66, K_67, K_68, K_69, K_70, K_71, K_72, K_73, K_74, K_76, K_77, K_86, K_87, K_88: KEYSW; MXOnly-1U-NoLED
K_14: KEYSW; MXOnly-1U
K_34, K_47: KEYSW; MXOnly-1.5U-NoLED
K_51: KEYSW; MXOnly-1.75U
K_63, K_64: KEYSW; MXOnly-2.25U-NoLED
K_75: KEYSW; MXOnly-1.75U-NoLED
K_78, K_79, K_80, K_82, K_83, K_84, K_85: 1.25; MXOnly-1.25U-NoLED
K_81: 6.25; MXOnly-6.25U-ReversedStabilizers-NoLED
K_130: MX-NoLED; MXOnly-2U-NoLED
K_151: MX-NoLED; MXOnly-1.25U-FLIPPED
K_175: MX-NoLED; MXOnly-2.75U-NoLED
K_178, K_180, K_183, K_185: ~1.5; MXOnly-1.5U-NoLED
K_179, K_184: ~1; MXOnly-1U-NoLED
K_181: ~7; MXOnly-7U-ReversedStabilizers-NoLED
R1: 10k; R_0603_1608Metric; LCSC C25804
R2: 1.5k; R_0603_1608Metric; LCSC C22843
R3, R4: 680; R_0603_1608Metric; LCSC C23228
U1: SRV05-4; SOT-23-6; LCSC C85364
U2: XC6206P332MR; SOT-23; LCSC C5446
U3: STM32F103C8Tx; LQFP-48_7x7mm_P0.5mm
Y1: 8MHz; Crystal_SMD_5032-2Pin_5.0x3.2mm; LCSC C115962

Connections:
+5V: C11.2, F1.1, U1.5 (VP), U2.3 (VI)
BOOT0: R1.1, U3.44 (BOOT0)
D+: J1.2, R2.2, U1.6 (IO4), U3.33 (PA12)
D-: J1.3, U1.4 (IO3), U3.32 (PA11)
GND: C1.2, C2.2, C3.2, C4.2, C5.2, C6.2, C7.2, C8.2, C9.2, C10.2, C11.1, C12.2, J1.4, J5.1, K_14.4 (LEDGND), K_51.4 (LEDGND), K_151.4 (LEDGND), R1.2, U1.2 (VN), U2.1 (GND), U3.8 (VSSA), U3.23 (VSS), U3.35 (VSS), U3.47 (VSS)
LED_CAPS: K_51.3 (LED), K_151.3 (LED), R3.1
LED_SCROLL: K_14.3 (LED), R4.2
NRST: C8.1, U3.7 (NRST)
unnamed: C9.1, U3.5 (PD0), Y1.1
unnamed: C10.1, U3.6 (PD1), Y1.2
unnamed: D_0.2 (A), K_0.2 (ROW)
unnamed: D_1.2 (A), K_1.2 (ROW)
unnamed: D_2.2 (A), K_2.2 (ROW)
unnamed: D_3.2 (A), K_3.2 (ROW)
unnamed: D_4.2 (A), K_4.2 (ROW)
unnamed: D_5.2 (A), K_5.2 (ROW)
unnamed: D_6.2 (A), K_6.2 (ROW)
unnamed: D_7.2 (A), K_7.2 (ROW)
unnamed: D_8.2 (A), K_8.2 (ROW)
unnamed: D_9.2 (A), K_9.2 (ROW)
unnamed: D_10.2 (A), K_10.2 (ROW)
unnamed: D_11.2 (A), K_11.2 (ROW)
unnamed: D_12.2 (A), K_12.2 (ROW)
unnamed: D_13.2 (A), K_13.2 (ROW)
unnamed: D_14.2 (A), K_14.2 (ROW)
unnamed: D_15.2 (A), K_15.2 (ROW)
unnamed: D_16.2 (A), K_16.2 (ROW)
unnamed: D_17.2 (A), K_17.2 (ROW)
unnamed: D_18.2 (A), K_18.2 (ROW)
unnamed: D_19.2 (A), K_19.2 (ROW)
unnamed: D_20.2 (A), K_20.2 (ROW)
unnamed: D_21.2 (A), K_21.2 (ROW)
unnamed: D_22.2 (A), K_22.2 (ROW)
unnamed: D_23.2 (A), K_23.2 (ROW)
unnamed: D_24.2 (A), K_24.2 (ROW)
unnamed: D_25.2 (A), K_25.2 (ROW)
unnamed: D_26.2 (A), K_26.2 (ROW)
unnamed: D_27.2 (A), K_27.2 (ROW)
unnamed: D_28.2 (A), K_28.2 (ROW)
unnamed: D_29.2 (A), K_29.2 (ROW)
unnamed: D_30.2 (A), K_30.2 (ROW), K_130.2 (ROW)
unnamed: D_31.2 (A), K_31.2 (ROW)
unnamed: D_32.2 (A), K_32.2 (ROW)
unnamed: D_33.2 (A), K_33.2 (ROW)
unnamed: D_34.2 (A), K_34.2 (ROW)
unnamed: D_35.2 (A), K_35.2 (ROW)
unnamed: D_36.2 (A), K_36.2 (ROW)
unnamed: D_37.2 (A), K_37.2 (ROW)
unnamed: D_38.2 (A), K_38.2 (ROW)
unnamed: D_39.2 (A), K_39.2 (ROW)
unnamed: D_40.2 (A), K_40.2 (ROW)
unnamed: D_41.2 (A), K_41.2 (ROW)
unnamed: D_42.2 (A), K_42.2 (ROW)
unnamed: D_43.2 (A), K_43.2 (ROW)
unnamed: D_44.2 (A), K_44.2 (ROW)
unnamed: D_45.2 (A), K_45.2 (ROW)
unnamed: D_46.2 (A), K_46.2 (ROW)
unnamed: D_47.2 (A), K_47.2 (ROW)
unnamed: D_48.2 (A), K_48.2 (ROW)
unnamed: D_49.2 (A), K_49.2 (ROW)
unnamed: D_50.2 (A), K_50.2 (ROW)
unnamed: D_51.2 (A), K_51.2 (ROW), K_151.1 (COL)
unnamed: D_52.2 (A), K_52.2 (ROW)
unnamed: D_53.2 (A), K_53.2 (ROW)
unnamed: D_54.2 (A), K_54.2 (ROW)
unnamed: D_55.2 (A), K_55.2 (ROW)
unnamed: D_56.2 (A), K_56.2 (ROW)
unnamed: D_57.2 (A), K_57.2 (ROW)
unnamed: D_58.2 (A), K_58.2 (ROW)
unnamed: D_59.2 (A), K_59.2 (ROW)
unnamed: D_60.2 (A), K_60.2 (ROW)
unnamed: D_61.2 (A), K_61.2 (ROW)
unnamed: D_62.2 (A), K_62.2 (ROW)
unnamed: D_63.2 (A), K_63.2 (ROW)
unnamed: D_64.2 (A), K_64.2 (ROW)
unnamed: D_65.2 (A), K_65.2 (ROW)
unnamed: D_66.2 (A), K_66.2 (ROW)
unnamed: D_67.2 (A), K_67.2 (ROW)
unnamed: D_68.2 (A), K_68.2 (ROW)
unnamed: D_69.2 (A), K_69.2 (ROW)
unnamed: D_70.2 (A), K_70.2 (ROW)
unnamed: D_71.2 (A), K_71.2 (ROW)
unnamed: D_72.2 (A), K_72.2 (ROW)
unnamed: D_73.2 (A), K_73.2 (ROW)
unnamed: D_74.2 (A), K_74.2 (ROW)
unnamed: D_75.2 (A), K_75.2 (ROW), K_175.2 (ROW)
unnamed: D_76.2 (A), K_76.2 (ROW)
unnamed: D_77.2 (A), K_77.2 (ROW)
unnamed: D_78.2 (A), K_78.2 (ROW), K_178.2 (ROW)
unnamed: D_79.2 (A), K_79.2 (ROW), K_179.2 (ROW)
unnamed: D_80.2 (A), K_80.2 (ROW), K_180.2 (ROW)
unnamed: D_81.2 (A), K_81.2 (ROW), K_181.2 (ROW)
unnamed: D_82.2 (A), K_82.2 (ROW)
unnamed: D_83.2 (A), K_83.2 (ROW), K_183.2 (ROW)
unnamed: D_84.2 (A), K_84.2 (ROW), K_184.2 (ROW)
unnamed: D_85.2 (A), K_85.2 (ROW), K_185.2 (ROW)
unnamed: D_86.2 (A), K_86.2 (ROW)
unnamed: D_87.2 (A), K_87.2 (ROW)
unnamed: D_88.2 (A), K_88.2 (ROW)
unnamed: R3.2, U3.13 (PA3)
unnamed: R4.1, U3.41 (PB5)
SWDCLK: J4.1, U3.37 (PA14)
SWDIO: J3.1, U3.34 (PA13)
VBAT: C1.1, C2.1, C3.1, C4.1, C5.1, C6.1, C7.1, C12.1, J2.1, R2.1, U2.2 (VO), U3.1 (VBAT), U3.9 (VDDA), U3.24 (VDD), U3.36 (VDD), U3.48 (VDD)
VBUS: F1.2, J1.1
col0: K_0.1 (COL), K_16.1 (COL), K_34.1 (COL), K_51.1 (COL), K_78.1 (COL), K_151.2 (ROW), K_178.1 (COL), U3.31 (PA10)
col1: K_17.1 (COL), K_64.1 (COL), K_79.1 (COL), K_179.1 (COL), U3.30 (PA9)
col2: K_1.1 (COL), K_18.1 (COL), K_35.1 (COL), K_52.1 (COL), K_65.1 (COL), U3.29 (PA8)
col3: K_2.1 (COL), K_19.1 (COL), K_36.1 (COL), K_53.1 (COL), K_66.1 (COL), K_80.1 (COL), K_180.1 (COL), U3.28 (PB15)
col4: K_3.1 (COL), K_20.1 (COL), K_37.1 (COL), K_54.1 (COL), K_67.1 (COL), U3.27 (PB14)
col5: K_4.1 (COL), K_21.1 (COL), K_38.1 (COL), K_55.1 (COL), K_68.1 (COL), U3.26 (PB13)
col6: K_22.1 (COL), K_39.1 (COL), K_56.1 (COL), K_69.1 (COL), K_81.1 (COL), K_181.1 (COL), U3.25 (PB12)
col7: K_5.1 (COL), K_23.1 (COL), K_40.1 (COL), K_57.1 (COL), K_70.1 (COL), U3.21 (PB10)
col8: K_6.1 (COL), K_24.1 (COL), K_41.1 (COL), K_58.1 (COL), K_71.1 (COL), U3.20 (PB2)
col9: K_7.1 (COL), K_25.1 (COL), K_42.1 (COL), K_59.1 (COL), K_72.1 (COL), U3.19 (PB1)
col10: K_8.1 (COL), K_26.1 (COL), K_43.1 (COL), K_60.1 (COL), K_73.1 (COL), K_82.1 (COL), U3.18 (PB0)
col11: K_9.1 (COL), K_27.1 (COL), K_44.1 (COL), K_61.1 (COL), K_74.1 (COL), K_83.1 (COL), K_183.1 (COL), U3.17 (PA7)
col12: K_10.1 (COL), K_28.1 (COL), K_45.1 (COL), K_62.1 (COL), U3.16 (PA6)
col13: K_11.1 (COL), K_29.1 (COL), K_46.1 (COL), K_63.1 (COL), K_75.1 (COL), K_84.1 (COL), K_175.1 (COL), K_184.1 (COL), U3.15 (PA5)
col14: K_12.1 (COL), K_30.1 (COL), K_47.1 (COL), K_76.1 (COL), K_85.1 (COL), K_130.1 (COL), K_185.1 (COL), U3.12 (PA2)
col15: K_13.1 (COL), K_31.1 (COL), K_48.1 (COL), K_86.1 (COL), U3.2 (PC13)
col16: K_14.1 (COL), K_32.1 (COL), K_49.1 (COL), K_77.1 (COL), K_87.1 (COL), U3.46 (PB9)
col17: K_15.1 (COL), K_33.1 (COL), K_50.1 (COL), K_88.1 (COL), U3.39 (PB3)
row0: D_0.1 (K), D_1.1 (K), D_2.1 (K), D_3.1 (K), D_4.1 (K), D_5.1 (K), D_6.1 (K), D_7.1 (K), D_8.1 (K), D_9.1 (K), D_10.1 (K), D_11.1 (K), D_12.1 (K), D_13.1 (K), D_14.1 (K), D_15.1 (K), U3.42 (PB6)
row1: D_16.1 (K), D_17.1 (K), D_18.1 (K), D_19.1 (K), D_20.1 (K), D_21.1 (K), D_22.1 (K), D_23.1 (K), D_24.1 (K), D_25.1 (K), D_26.1 (K), D_27.1 (K), D_28.1 (K), D_29.1 (K), D_30.1 (K), D_31.1 (K), D_32.1 (K), D_33.1 (K), U3.40 (PB4)
row2: D_34.1 (K), D_35.1 (K), D_36.1 (K), D_37.1 (K), D_38.1 (K), D_39.1 (K), D_40.1 (K), D_41.1 (K), D_42.1 (K), D_43.1 (K), D_44.1 (K), D_45.1 (K), D_46.1 (K), D_47.1 (K), D_48.1 (K), D_49.1 (K), D_50.1 (K), U3.38 (PA15)
row3: D_51.1 (K), D_52.1 (K), D_53.1 (K), D_54.1 (K), D_55.1 (K), D_56.1 (K), D_57.1 (K), D_58.1 (K), D_59.1 (K), D_60.1 (K), D_61.1 (K), D_62.1 (K), D_63.1 (K), U3.14 (PA4)
row4: D_64.1 (K), D_65.1 (K), D_66.1 (K), D_67.1 (K), D_68.1 (K), D_69.1 (K), D_70.1 (K), D_71.1 (K), D_72.1 (K), D_73.1 (K), D_74.1 (K), D_75.1 (K), D_76.1 (K), D_77.1 (K), U3.45 (PB8)
row5: D_78.1 (K), D_79.1 (K), D_80.1 (K), D_81.1 (K), D_82.1 (K), D_83.1 (K), D_84.1 (K), D_85.1 (K), D_86.1 (K), D_87.1 (K), D_88.1 (K), U3.43 (PB7)

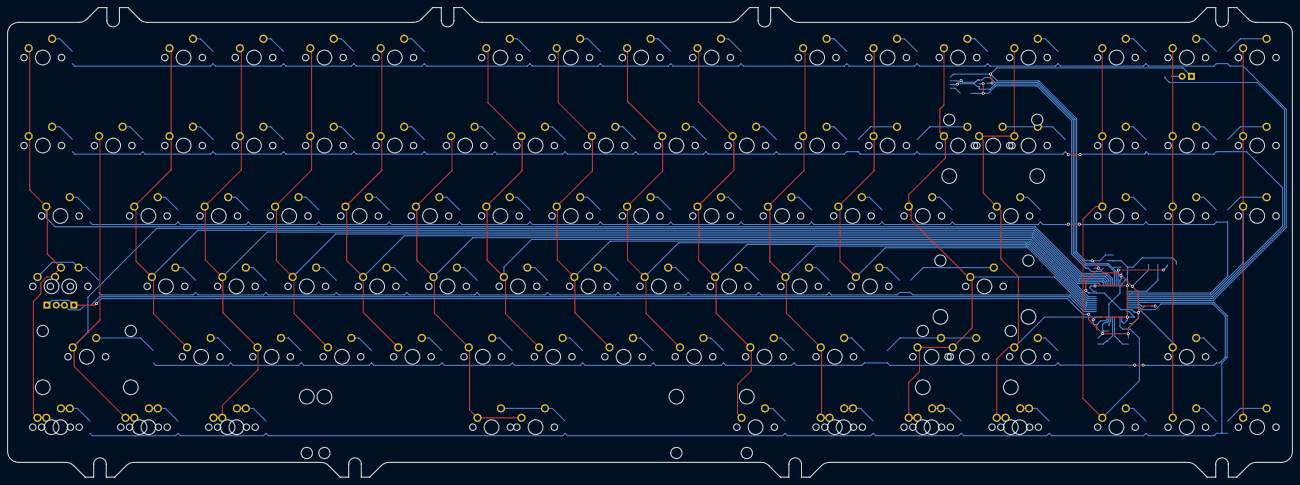
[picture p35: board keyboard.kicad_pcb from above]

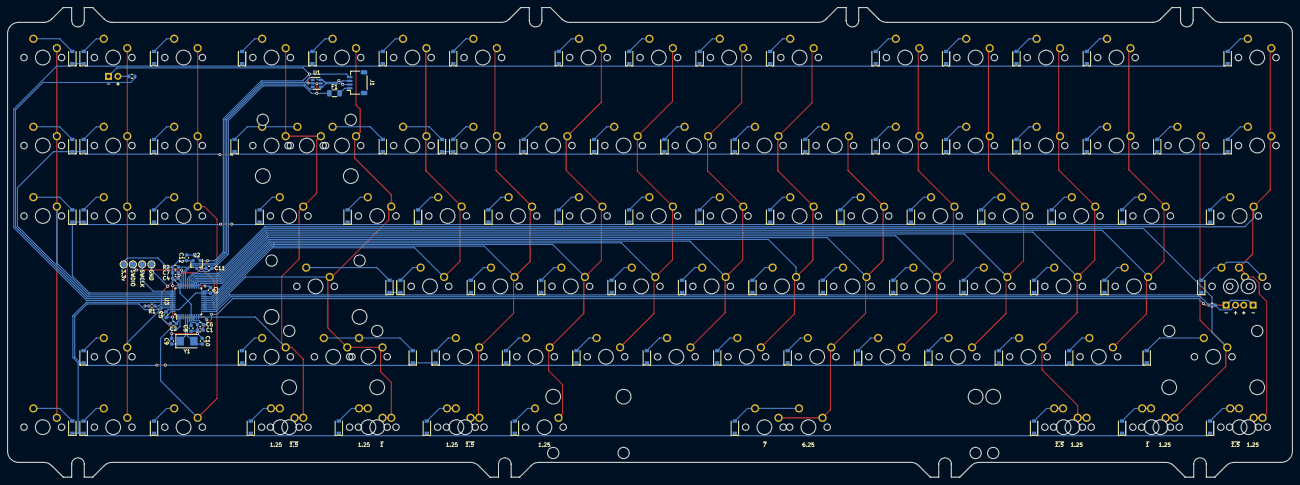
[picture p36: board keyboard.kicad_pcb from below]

Board: 2 copper layers, 347.7 x 127.1 mm, 214 parts (115 on the bottom side), 129 nets.
